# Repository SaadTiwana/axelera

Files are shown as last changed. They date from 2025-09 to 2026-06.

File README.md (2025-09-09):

# axelera
Notes and files for work on Axelera Metix M.2 on RK3588 board and using it to build an intelligent Marine surveillance Gimbal system.

The work was done as part of Axelera's Pioneer 10 : AI vision challenge.

https://community.axelera.ai/groups/project-challenge-recognize-react-27

The indidual directories contain all the files for each aspect of the project.

Read more details about the project here:

[PART 1]
https://community.axelera.ai/project-challenge-recognize-react-27/sauron-intelligent-marine-surveillance-system-pioneer-10-project-final-submission-part-one-1020

[PART 2]
https://community.axelera.ai/project-challenge-recognize-react-27/sauron-intelligent-marine-surveillance-system-pioneer-10-project-final-submission-part-two-1023

[PART 3]
https://community.axelera.ai/project-challenge-recognize-react-27/sauron-intelligent-marine-surveillance-system-pioneer-10-project-final-submission-part-three-1024

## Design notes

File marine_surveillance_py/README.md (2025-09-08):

# Maritime Surveillance System

A robust Python-based maritime surveillance system running on RK3588 with Axelera Metis M.2 AI accelerator, featuring real-time object detection, precise gimbal control, and intelligent restricted area monitoring with audio alerts.

## 🏗️ System Architecture

```
┌─────────────────┐    ┌─────────────────┐    ┌─────────────────┐
│   STM32 Gimbal  │◄──►│   RK3588 SBC    │◄──►│  USB Camera     │
│   Controller    │    │  ┌────────────┐ │    │  (/dev/video20) │
└─────────────────┘    │  │ Axelera     │ │    └─────────────────┘
                       │  │ Metis M.2   │ │
                       │  │ AI Engine   │ │
                       │  └────────────┘ │
                       └─────────────────┘
```

## 📁 Project Structure

```
Axelera_program/
├── main.py                 # 🚀 Main application orchestrator with alarm management
├── config.py              # ⚙️ Configuration management and validation
├── uart_comm.py           # 📡 UART communication with STM32 gimbal
├── scan_planner.py        # 🗺️ FOV-based scan planning with serpentine patterns
├── camera.py              # 📷 Camera capture with buffer management
├── detector.py            # 🎯 AI object detection with coordinate conversion
├── logger.py              # 📊 Detection logging and data persistence
├── monitor.py             # 🚨 Restricted area monitoring with audio alerts
├── settings.json          # 🔧 Configuration file with current settings
├── requirements.txt       # 📦 Python dependencies
├── documentation/         # 📚 System documentation and diagrams
├── utilities/             # 🛠️ Testing and utility scripts
└── README.md              # 📖 This documentation
```

## 🚀 Quick Start

### Prerequisites

1. **Hardware Requirements:**
   - RK3588 single-board computer
   - Axelera Metis M.2 AI accelerator
   - USB camera (tested with /dev/video20)
   - STM32-based gimbal controller
   - Bluetooth speaker (optional, for audio warnings)

2. **Software Requirements:**
   ```bash
   pip install opencv-python numpy pyserial
   pip install degirum  # Degirum SDK for object detection
   ```
Note: The voyager-sdk needs to be installed on the system and Metis device working properly. If the degirum sdk cannot find the Metis device, type "axdevice --refresh" from inside the voyager-sdk's venv.

### Configuration

Edit `settings.json` to configure your system:

```json
{
  "camera": {
    "device": "/dev/video20",
    "resolution": [1920, 1280],
    "fov_degrees": [8.28, 5.53]
  },
  "scan_area": {
    "azimuth_range": [-20.0, 20.0],
    "elevation_range": [-20.0, 0.0],
    "min_overlap_percentage": 0.1,
    "scan_cycles": 1
  },
  "restricted_areas": [
    {
      "name": "Bridge Entrance",
      "polygon": [
        [-45.0, -10.0],
        [-30.0, -5.0],
        [-15.0, -10.0],
        [-30.0, -15.0]
      ],
      "warning_threshold_seconds": 30,
      "classes": ["boat_small", "boat_medium"]
    },
    {
      "name": "Marine Sanctuary",
      "polygon": [
        [-45.0, -10.0],
        [-30.0, -5.0],
        [-15.0, -10.0],
        [-30.0, -15.0]
      ],
      "warning_threshold_seconds": 30,
      "classes": ["boat_large", "ship"]
    }
  ]
}
```

### Running the System

#### Continuous Monitoring Mode (Default)
```bash
python3 main.py
```

#### Single Scan Mode
```bash
python3 main.py --mode single
```

#### Hardware Testing Only
```bash
python3 main.py --test
```

#### Custom Configuration
```bash
python3 main.py --config my_settings.json --mode continuous
```

#### Live Video Feed (Camera Focusing)
```bash
python3 main.py --live-video
```
Use this mode to focus and adjust your camera before starting surveillance. The system will:
- Display a live video feed with a crosshair for focusing
- Show camera resolution and FPS information
- Allow you to adjust camera settings while viewing the feed
- Press Ctrl+C in the terminal to exit and return to normal operation

## ⚙️ Configuration Details

### Camera Configuration
- **device**: Video device path (e.g., `/dev/video20`)
- **resolution**: Camera resolution [width, height]
- **fov_degrees**: Camera field of view [azimuth, elevation] in degrees

### Scan Area Configuration
- **azimuth_range**: Azimuth scan range [min, max] in degrees
- **elevation_range**: Elevation scan range [min, max] in degrees
- **min_overlap_percentage**: Frame overlap percentage (0.0-1.0) for automatic step calculation from camera FOV
- **scan_cycles**: Number of complete scan cycles to perform (1/2/3/... or -1 for indefinite)

### Restricted Areas
- **name**: Human-readable area name
- **polygon**: List of [azimuth, elevation] points defining the area boundary
  - Supports any number of points (minimum 3 for a valid polygon)
  - Points should be specified in clockwise or counter-clockwise order
  - Supports complex shapes: triangles, rectangles, irregular polygons
  - Automatically closed by the system (connects last point to first)
- **warning_threshold_seconds**: Time threshold for triggering audio warnings
- **classes**: List of object classes to monitor (optional, monitors all classes if empty)
  - Example: `["boat_small", "boat_medium", "ship"]`
  - Only specified classes will trigger warnings in this area

### Gimbal Configuration
- **move_timeout_seconds**: Maximum time to wait for gimbal movement
- **settle_time_seconds**: Time to wait after movement for stabilization
- **max_retries**: Maximum retry attempts for failed movements

### Detection Configuration
- **model_path**: Path to Degirum model file
- **confidence_threshold**: Minimum confidence for detections (0.0-1.0)
- **tile_size**: Image tile size for processing large images
- **overlap**: Overlap between tiles (0.0-1.0)

## 🔧 Hardware Setup

### UART Connection
Connect the RK3588 UART to STM32:
- RK3588 TX → STM32 RX
- RK3588 RX → STM32 TX
- Ground connection
- Baud rate: 115200

### Camera Setup
1. Connect USB camera to RK3588
2. Verify device path: `ls /dev/video*`
3. Update `settings.json` with correct device path

### Audio Setup (Optional)
For Bluetooth speaker audio warnings:
```bash
# Install Bluetooth audio support
sudo apt-get install bluealsa

# Pair and connect Bluetooth speaker
bluetoothctl
# pair XX:XX:XX:XX:XX:XX
# connect XX:XX:XX:XX:XX:XX
```

## 📊 System Operation

### Scan Process
1. **Position Planning**: System calculates optimal scan positions
2. **Gimbal Movement**: Moves to each scan position with verification
3. **Image Capture**: Captures high-resolution image
4. **Object Detection**: Runs AI detection using Degirum SDK
5. **Data Logging**: Saves detections with position and timestamp
6. **Area Monitoring**: Checks for restricted area violations
7. **Audio Warnings**: Issues alerts for violations

### Detection Results
- **Real-time Display**: Shows detections on captured images
- **CSV Logging**: Saves all detections to timestamped files
- **Image Storage**: Saves annotated images for review
- **Statistics**: Tracks detection rates and patterns

## 🔍 Scan Planning and Execution

### Automatic Step Calculation
The system automatically calculates optimal scan steps based on:
- **Camera Field of View**: Uses actual camera FOV angles
- **Overlap Percentage**: Configurable frame overlap (default 10%)
- **Formula**: `step = FOV × (1 - overlap_percentage)`

Example: With 60° FOV and 10% overlap → step = 60° × 0.9 = 54°

### Vertical Serpentine Scan Pattern
- **Systematic Coverage**: Starts from top-left of scan area
- **Vertical Serpentine Movement**: Alternates direction on each column
  - Column 1: Top to bottom (down)
  - Column 2: Bottom to top (up)
  - Column 3: Top to bottom (down)
  - And so on...
- **Complete Coverage**: Ensures no gaps in surveillance area

### Scan Cycle Control
- **Finite Cycles**: Specify exact number of complete scans (1, 2, 3, etc.)
- **Indefinite Monitoring**: Set `scan_cycles: -1` for continuous operation
- **Progress Tracking**: Shows current cycle and total progress

### Restricted Area Handling
- **Full Coverage**: All positions in scan area are visited (no exclusions)
- **Monitoring vs Exclusion**: Restricted areas are monitored, not avoided
- **Class-Specific Alerts**: Only specified object classes trigger warnings per area
- **Flexible Polygons**: Support for complex shapes with 3+ vertices

## 🎯 Key Features

### Intelligent Scan Planning
- **FOV-based step calculation** using camera field of view and overlap percentage
- **Vertical serpentine scan pattern** for systematic coverage (top-left to bottom-right)
- **Automatic overlap management** to ensure no gaps in surveillance
- **Configurable scan cycles** (1-N cycles or indefinite monitoring)
- **Complete area coverage** including restricted zones (monitoring vs exclusion)

### Robust Gimbal Control
- **Position verification** after each movement with angle validation
- **Retry logic** for failed movements with configurable timeouts
- **Emergency stop** functionality with motor centering
- **UART communication** with CRC error checking and protocol validation

### Advanced Object Detection
- **Degirum SDK integration** for high-performance AI inference
- **Image tiling** for processing large images (1920x1280)
- **Coordinate system conversion** from normalized to azimuth/elevation angles
- **Confidence thresholding** to filter noise and false positives
- **Multi-class detection** for various maritime objects

### Restricted Area Monitoring
- **Polygon-based zones** supporting complex shapes (triangles to irregular polygons)
- **Class-specific monitoring** - monitor only specified object classes per area
- **Dwell time tracking** for persistent violations with configurable thresholds
- **Audio warnings** via Bluetooth speaker for immediate alerts
- **Visual alarm indicators** with red bounding boxes and status display
- **Comprehensive violation logging** with timestamps and object details

## 📈 Monitoring and Logging

### Real-time Statistics
- Detection counts and confidence scores
- Gimbal movement success rates
- System performance metrics
- Hardware status monitoring

### Data Export
- **CSV files** with detection data
- **Annotated images** for visual verification
- **System logs** for troubleshooting
- **Performance statistics** for optimization

## 🛠️ Troubleshooting

### Common Issues

#### 1. UART Communication Problems
```bash
# Check UART device
ls /dev/ttyS* /dev/ttyUSB*

# Test serial connection
python3 -c "import serial; s=serial.Serial('/dev/ttyS0', 115200, timeout=1); print('UART OK' if s.is_open else 'UART FAIL')"
```

#### 2. Camera Issues
```bash
# Check camera device
v4l2-ctl --list-devices
v4l2-ctl --list-formats-ext /dev/video20

# Test camera capture
ffmpeg -f v4l2 -i /dev/video20 -vframes 1 test.jpg

# Run comprehensive camera test
python3 utilities/camera_test.py
```

#### 3. Degirum SDK Issues
```bash
# Check Degirum installation (from inside degirum venv)
python3 -c "import degirum as dg; print('Degirum OK')"

degirum sys-info

# Verify model file
ls -la models/yolo_v5s_maritime
```

#### 4. Gimbal Movement Issues
- Check UART wiring and baud rate
- Verify STM32 is running and UARTProtocol is active
- Check gimbal angle limits in settings
- Monitor STM32 serial output for error messages

### Camera Testing and Debugging
The system includes comprehensive camera testing utilities:

```bash
# Run comprehensive camera test
python3 utilities/camera_test.py

# This tests:
# - Device existence and permissions
# - Multiple OpenCV backends (V4L2, ANY)
# - Different resolutions (640x480, 1280x720, 1920x1080, 1920x1280)
# - Frame capture capabilities
# - Camera properties and settings
# - Continuous capture stability
```

### Debug Mode
Enable detailed logging by modifying `settings.json`:
```json
{
  "logging": {
    "log_level": "DEBUG"
  }
}
```

### Camera Backend Fixes
If you encounter camera issues, the system automatically tries multiple OpenCV backends:
1. **V4L2 Backend** (recommended for Linux)
2. **ANY Backend** (auto-detection fallback)

The camera module includes:
- ✅ Multiple backend support
- ✅ Retry logic for failed captures
- ✅ Stabilization delays
- ✅ **Camera warm-up sequence** (discards first 10 frames)
- ✅ Comprehensive error handling
- ✅ Format and resolution testing

### Camera Warm-up Process
After opening the camera and setting resolution, the system automatically:
1. Waits 0.5 seconds for initial stabilization
2. Discards the first 10 frames to allow:
   - Auto-exposure adjustment
   - Auto-white balance stabilization
   - Auto-focus completion (if available)
   - Overall camera parameter optimization
3. Ensures consistent image quality for detection

## 🔧 API Reference

### GimbalController
```python
gimbal = GimbalController(config)
gimbal.connect()                    # Establish UART connection
gimbal.get_angles()                 # Get current angles (pitch, yaw)
gimbal.set_angles(pitch, yaw)       # Set target angles
gimbal.move_to_position(az, el)     # Move to azimuth/elevation
```

### ObjectDetector
```python
detector = ObjectDetector(config)
detector.initialize()               # Initialize Degirum model
detections = detector.detect_with_tiling(image)  # Run detection
```

### AreaMonitor
```python
monitor = AreaMonitor(config)
warnings = monitor.process_detections(detections, scan_pos)
```

## 📝 Development Notes

### Adding New Features
1. Create new module in appropriate file
2. Update `settings.json` for configuration
3. Integrate with main orchestrator in `main.py`
4. Add proper error handling and logging

### Performance Optimization
- **Automatic FOV-based step calculation** eliminates manual tuning
- **Overlap percentage adjustment** for coverage vs speed trade-off
- **Scan cycle configuration** for mission-specific operation duration
- **Class-specific monitoring** reduces false positive processing
- **Flexible polygon definitions** for precise restricted area boundaries
- Monitor CPU/GPU usage with Axelera tools

### Safety Considerations
- Implement proper emergency stop procedures
- Add watchdog timers for critical operations
- Validate all input parameters
- Handle hardware failures gracefully

## 📄 License

This project is part of the maritime surveillance system for RK3588 with Axelera Metis M.2.

## 🤝 Contributing

1. Fork the repository
2. Create a feature branch
3. Add comprehensive tests
4. Submit a pull request

## 📞 Support

For issues and questions:
1. Check the troubleshooting section
2. Review system logs
3. Verify hardware connections
4. Check configuration settings

---

**System Status**: ✅ Production Ready with Enhanced Features
**Hardware**: RK3588 + Axelera Metis M.2 + STM32 Gimbal Controller
**Software**: Python 3.8+ with Degirum SDK + OpenCV
**Key Features**: Coordinate conversion, audio alerts, visual alarms, robust error handling, real-time monitoring

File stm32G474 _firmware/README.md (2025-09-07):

STM32G474 firmware for the 2 axis gimbal

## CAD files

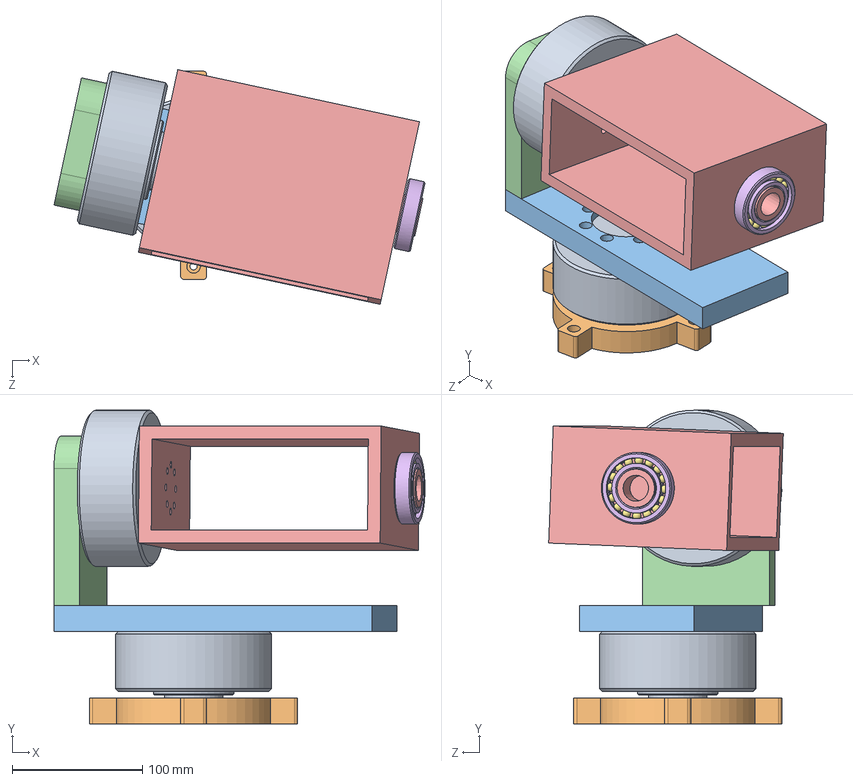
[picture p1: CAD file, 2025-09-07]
mechanical_design/GimbalAssembly.SLDASM
285.0 x 241.0 x 180.3 mm
RMD_L_12025 x 2
BottomBase
MiddleGimbalPart
VerticalMotorPlate
InnerGimbalPlatform
ball bearing(6006)-body.stp
ball bearing(6006)-ball.stp x 16

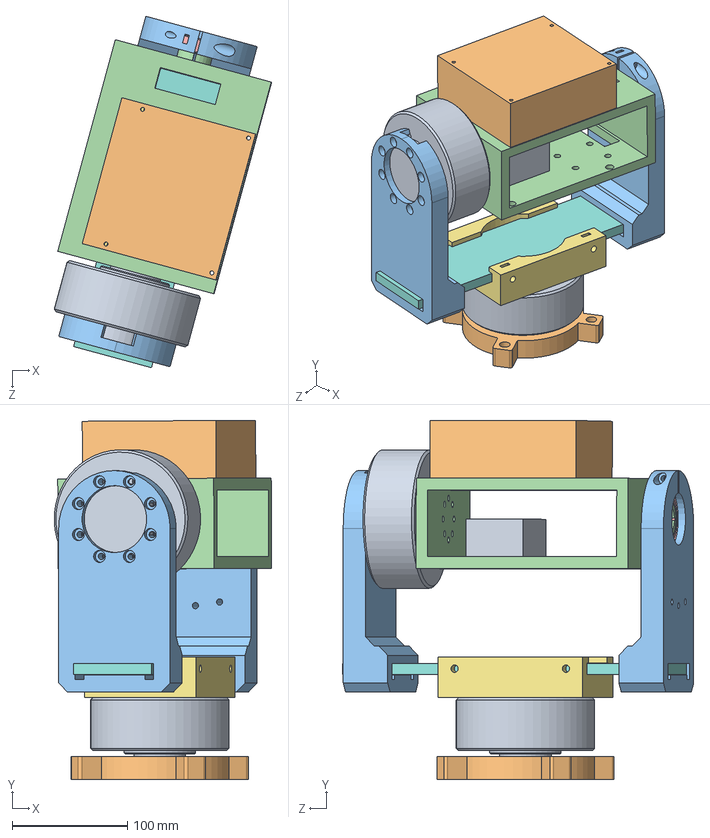
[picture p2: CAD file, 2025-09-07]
mechanical_design/GimbalAssembly_V2.SLDASM
188.4 x 311.0 x 304.5 mm
RMD_L_12025 x 2
BottomBase
VerticalMotorPlate x 2
InnerGimbalPlatform
ball bearing(6006)-body.stp
ball bearing(6006)-ball.stp x 16
YawMotorAttachment
AluminumBlackPlate
ControlBoard
AetinaRK3588_With15mmSpacers

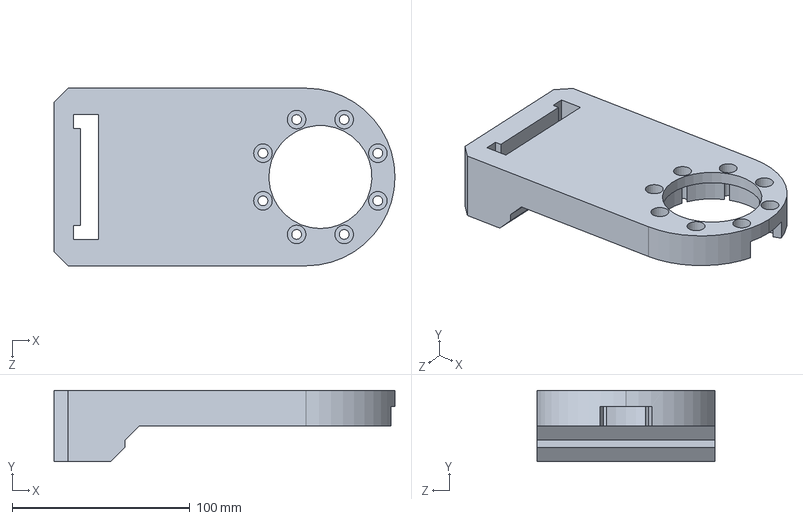
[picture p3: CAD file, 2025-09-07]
mechanical_design/VerticalMotorPlate.SLDPRT
192.0 x 40.0 x 100.0 mm

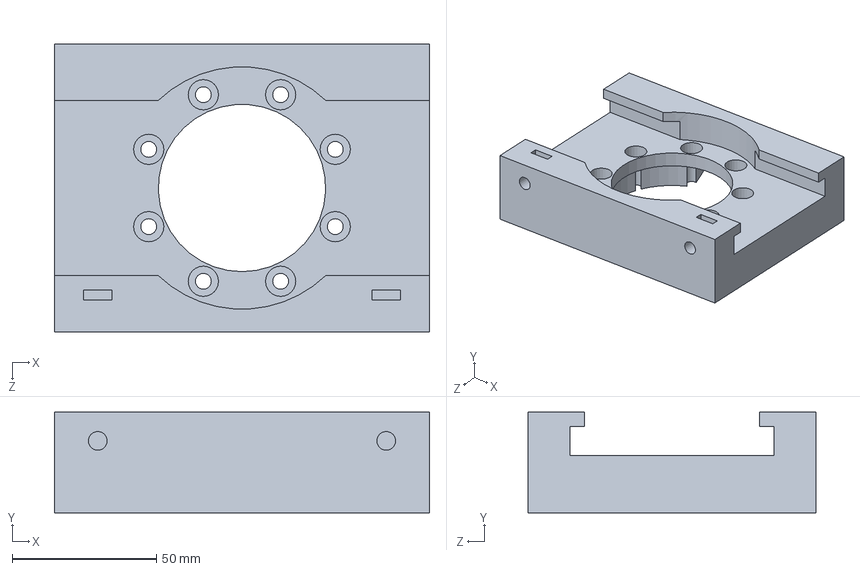
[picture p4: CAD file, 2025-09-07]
mechanical_design/YawMotorAttachment.SLDPRT
130.0 x 35.0 x 100.0 mm

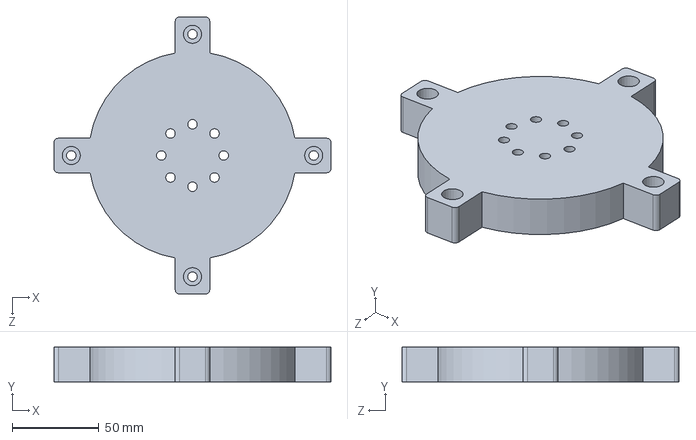
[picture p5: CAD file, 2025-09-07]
mechanical_design/BottomBase.SLDPRT
160.0 x 20.0 x 160.0 mm

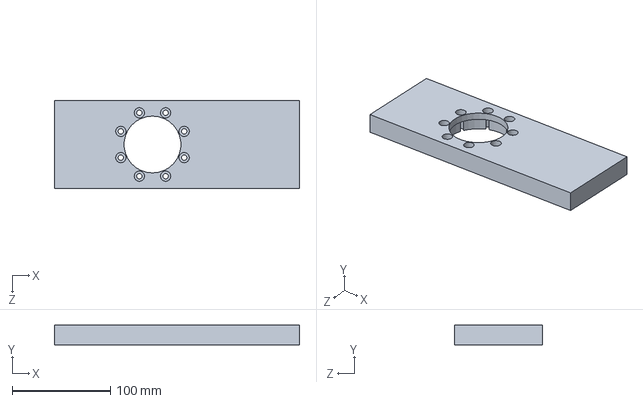
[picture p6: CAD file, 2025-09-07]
mechanical_design/MiddleGimbalPart.SLDPRT
250.0 x 20.0 x 90.0 mm

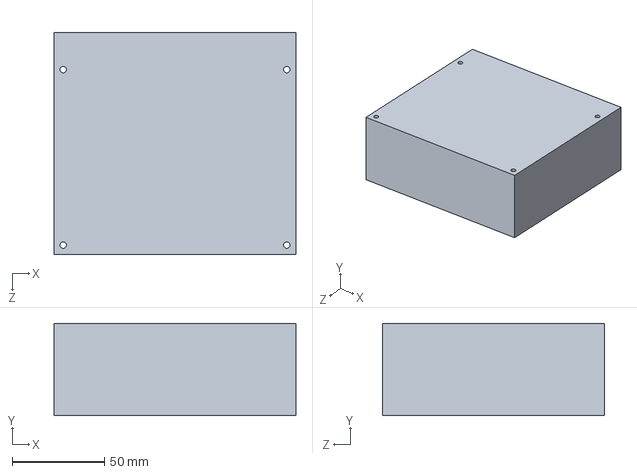
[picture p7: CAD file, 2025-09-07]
mechanical_design/AetinaRK3588_With15mmSpacers.SLDPRT
131.0 x 50.0 x 120.0 mm

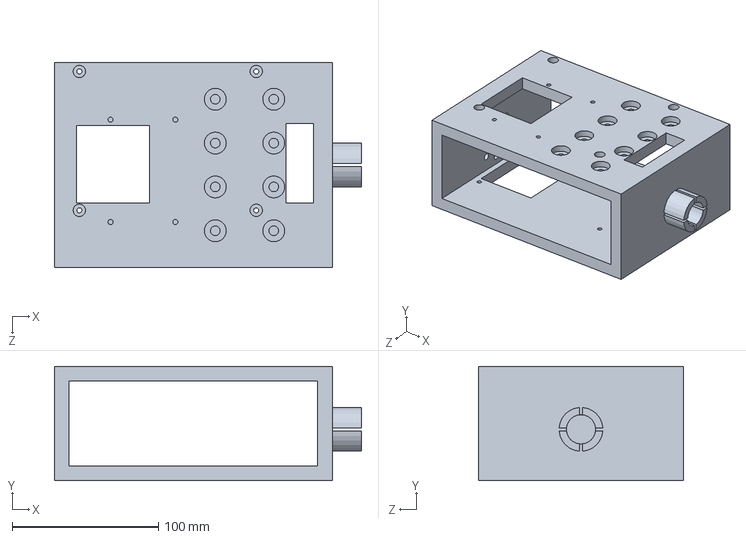
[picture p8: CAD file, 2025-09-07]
mechanical_design/InnerGimbalPlatform.SLDPRT
210.0 x 78.0 x 140.0 mm

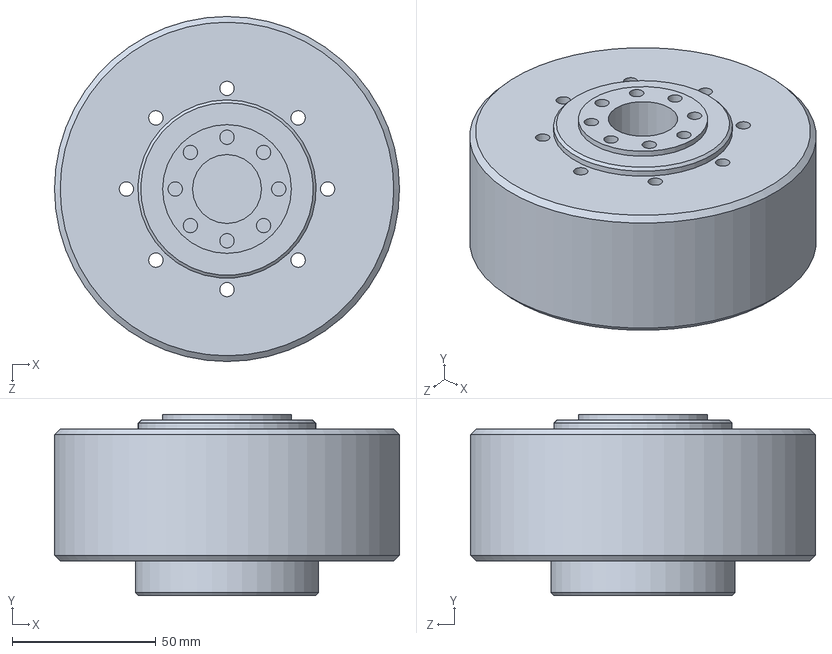
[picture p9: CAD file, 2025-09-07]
mechanical_design/RMD_L_12025.SLDPRT
120.0 x 63.0 x 120.0 mm

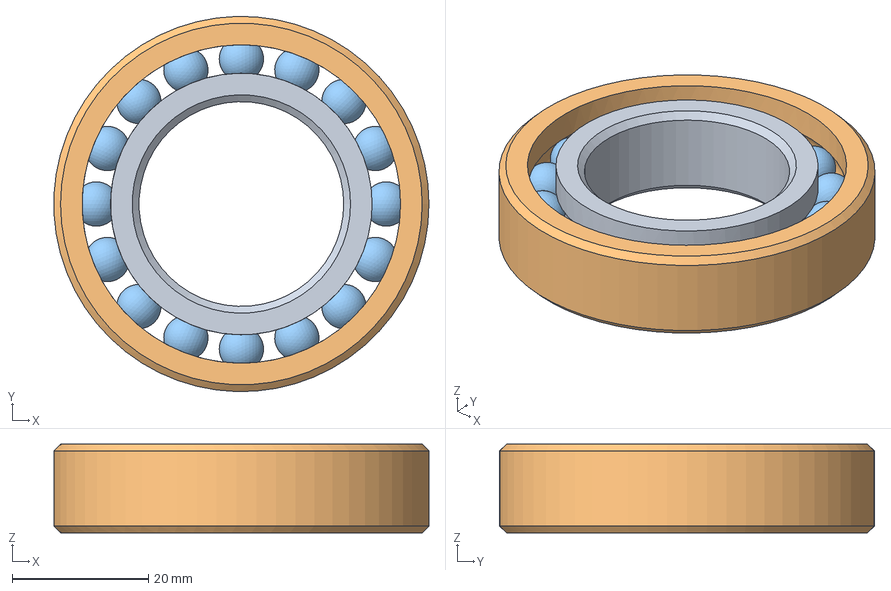
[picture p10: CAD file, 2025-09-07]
mechanical_design/ball bearing(6006).stp
55.0 x 55.0 x 13.0 mm
ball bearing(6006)-body
ball bearing(6006)-ball x 16

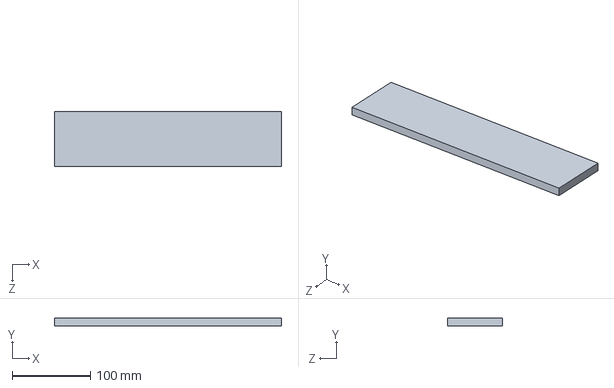
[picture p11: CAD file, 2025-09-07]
mechanical_design/AluminumBlackPlate.SLDPRT
290.0 x 9.60 x 70.0 mm

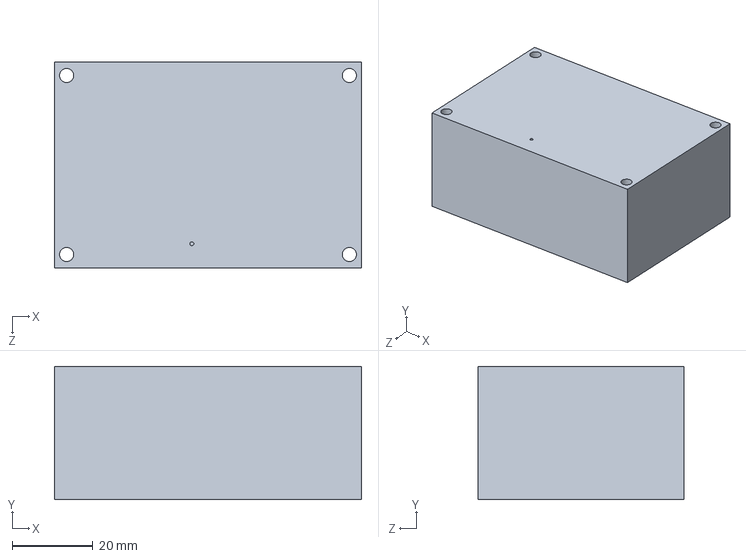
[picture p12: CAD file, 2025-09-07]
mechanical_design/ControlBoard.SLDPRT
76.0 x 33.0 x 51.0 mm

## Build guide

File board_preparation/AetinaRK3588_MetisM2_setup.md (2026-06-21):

# Introduction

This file details the full procedure to (re-)image an Aetina RK3588 board fitted with Axelera Metis M.2 accelerator card and prepare it for usage. Information here has been gathered from Axelera help pages, community posts and also from information shared by the very helpful [Shabaz](https://github.com/shabaz123) . I had the 16GB RAM version of the Aetina RK3588 board. All the instructions will also hold for the 8GB version, except that swapfile should also be enabled for the 8GB version.

# Flashing the board

These instructions hold for the Aetina RK3588 board. The instructions are taken from the Axelera page:

https://support.axelera.ai/hc/en-us/articles/25556440050194-System-Imaging-Guide-Aetina-RK3588

A Ubuntu x86/x64 "host" system is needed for this procedure (the RK3588 board cannot itself be used for this). I used ubuntu 22 "live" usb disk running on a laptop (this prevents needing to install the OS to the machine). I also tried with a Virtual Machine (Vmware), which worked fine as well.

Inside the host ubuntu, download the image (get latest link from page above, in case there is a newer version). Below is link to image as of July 2025:

https://axelera-public.s3.eu-central-1.amazonaws.com/host-images/v1.0.0-a6-0-g544580a49/Aetina-ubuntu-22.04-v1.1.tgz

`wget https://axelera-public.s3.eu-central-1.amazonaws.com/host-images/v1.0.0-a6-0-g544580a49/Aetina-ubuntu-22.04-v1.1.tgz`

After downloading the file, do this:
```
sudo tar -xvzf Aetina-ubuntu-22.04-v1.1.tgz 
cd rockdev
chmod +x upgrade_tool
```

Install jumpter between pins 2,3 of DEBUG3 header on board, connect USB-C port of board to host system (using USB-A to USB-C cable). Then power on the board. After several seconds, remove the jumper from the board. 

Run following commands to check board is connected and status:

`./upgrade_tool LD` 

Axelera link mentioned the board should appear like this, in "Loader" mode:

>List of rockusb connected(1)
>
>DevNo=1 Vid=0x2207,Pid=0x350b,LocationID=31     Mode=Loader     SerialNo=1da8b74954605d1d

However, my board was going into "Maskrom" mode only. 

>List of rockusb connected(1)
>
>DevNo=1 Vid=0x2207,Pid=0x350b,LocationID=11     Mode=Maskrom     SerialNo=

However, I found out that it didn't matter actually. I was able to proceed with firmware update as normal. To start the flashing, use command:

`./flash.sh`

The process will finish like this (last few lines only)
>Download image ok.
>
>---- reset device ----
>
>Reset Device OK. 

Now, remove USB-C cable and unplug power, then plug it back in (power-cycle, and not just restart).

Connect to Mouse/Keyboard, HDMI cable and power on.

# Setting Default User and Auto-login

By default, the image comes with two users "firefly" and "aetina", and the board boots into "firefly" user on power up. Since I noticed that a lot of documentation uses the "aetina" user, I decided it's best to set "aetina" as the default user so that the board conveniently boots into it on power up.

The relevant setting is in the file `/etc/lightdm/lightdm.conf.d/20-autologin.conf`. Open this file using any text editor (vi/vim/nano/gEdit, etc) and look for the line `autologin-user=firefly`. Change it to `autologin-user=aetina`, and then reboot the board `sudo reboot`.

Once the board reboots, it will auto-login into the "aetina" user, which can be confirmed by executing the command `whoami` in a terminal. At this point, if you want to remove the firefly user completely, type following command in the terminal:

`sudo deluser --remove-home firefly`

This will remove (delete) the user "firefly" and also remove the home folder for the user (this helps recover some space on the flash).

# Getting Wifi + BT to work

Before going further, it makes things easy to connect to internet with an Ethernet cable (can also share internet from the Ubuntu or windows host PC if router is far). 

Another easy alternative for getting internet access is using the RTL8188 USB dongle provided by Axelera to connect to internet. Use instructions provided by Shabaz:

https://github.com/shabaz123/rtl8188eus/blob/master/README.md 

Note that speed from this dongle is not great (works on 2.4Ghz only) but ok to get internet quickly.

To get better speed, I installed a RTL8822CE based M.2 card (5.8Ghz+ 2.4Ghz Wifi, Bluetooth) on the back side of the board - Credit to Shabaz for the idea!

The driver for this is available in the "linux-firmware" package inside the linux git. However ,the whole package is more than a GB in size and not suitable to download to an embedded board like this. Instad, we can manually download and install the driver files.

Download the latest driver files from the linux repository (click file name, then download raw/plain - very important to do like this. Right-click->save does not download file correctly):

https://git.kernel.org/pub/scm/linux/kernel/git/firmware/linux-firmware.git/tree/rtw88

We only need two files:
>rtw8822c_fw.bin
>
>rtw8822c_wow_fw.bin

Alternatively, we can download via wget in terminal (link used are raw/plain file links, which downloads the files correctly):
```
wget https://git.kernel.org/pub/scm/linux/kernel/git/firmware/linux-firmware.git/plain/rtw88/rtw8822c_fw.bin
wget https://git.kernel.org/pub/scm/linux/kernel/git/firmware/linux-firmware.git/plain/rtw88/rtw8822c_wow_fw.bin
```

Next, with a terminal open in the directory where files were downloaded, run following commands:
```
sudo mkdir -p /lib/firmware/rtw88
sudo mv rtw88*.bin /lib/firmware/rtw88/
sudo depmod -a
sudo modprobe rtw88_8822ce
sudo reboot
```

The wifi card should be functioning now and you can search and connect to a network using the toolbar on top-right of Ubuntu GUI. 

For more detailed instructions, refer to:

https://github.com/shabaz123/axelera/tree/main/rtw88

For this card, I did not have to do anything to get the bluetooth to work - it worked out of the box.

# Set up SD card to extend storage and swap file
The RK3588 board comes with 32GB of Flash storage. After the ubuntu 22 image is installed on the board it only leaves ~10GB storage available, which is quite small and fills up really quickly. Hence extending it with a fast SD card or a M.2 SSD is very important. 

Main article to refer to:

https://support.axelera.ai/hc/en-us/articles/25556514922514-Solving-Storage-Space-Issues-on-Aetina-Evaluation-System

Some commands have been modified, though. 

Insert sdcard, and confirm presence by using command:

`lsblk -f`

The SD card will appear as mmcblk1p1 (or something similar?). In instructions below we will assume it is "mmcblk1p1".

```
sudo mkfs.ext4 -F -L microsd /dev/mmcblk1p1

cd /mnt
sudo mkdir microsd
sudo bash -c "echo \"LABEL=microsd /mnt/microsd ext4 defaults,user,exec,nofail 0 2\" >> /etc/fstab"
sudo mount /mnt/microsd
sudo chown aetina:aetina /mnt/microsd
```

Next, we want to link some of the main folders used by Axelera sdk, etc to the SD card so that the they dont end up using up the EMMC.

First we remove the /axelera folder and recreate as a symbolic link to the SD card
```
sudo rm -rf /axelera
mkdir /mnt/microsd/axelera
sudo ln -s /mnt/microsd/axelera /axelera

```

Next, to prevent Axelera SDk from filling up the /home/aetina/.cache/axelera/data folder, we link it to SD card also

```
sudo mkdir /mnt/microsd/aetina_cache_axelera
sudo chown aetina:aetina /mnt/microsd/aetina_cache_axelera

ln -s /mnt/microsd/aetina_cache_axelera /home/aetina/.cache/axelera
mkdir /mnt/microsd/aetina_cache_axelera/data

```

# Setting up SWAP file

Setting up SWAP file is recommended for the 8GB RAM version of the Aetina RK3588 board. However, I found that the board shipped to me by Axelera is the 16GB RAM Aetina RK3588 boards, hence this was not needed. This can be confirmed by typing the following in a console:

`free -h`

Look at the 'total' under command output. In my case, it showed "15Gi" which points to it having 16GB RAM.

For the 8GB version board, follow the procedure at this link:
https://support.axelera.ai/hc/en-us/articles/25556440050194-System-Imaging-Guide-Aetina-RK3588

# Install Docker

Note: Don't install Docker until you've mounted either a microSD card, or M.2 SSD as extra storage, and created /axelera as a symbolic link to that storage. Otherwise, Docker will make use of the SBC's embedded memory, which is insufficient.

Once you have mounted the extra storage and created the /axelera link, follow the procedure here:

https://docs.docker.com/engine/install/ubuntu/

Axelera recommends using the method under "Install using the apt repository" heading on the linked page.

## Resolving ‘you have held broken packages’
When you start typing the Docker installation steps, you may see a **you have held broken packages** message. The solution is to type the following as a user (e.g. as aetina user), and then you can re-do the Docker installation.

```
apt-mark showhold | tee ~/apt-holds.backup
sudo xargs -r apt-mark unhold < ~/apt-holds.backup
sudo apt update
sudo apt --fix-broken install
sudo apt full-upgrade
rm ~/apt-holds.backup
```

# Install Voyager SDK

The latest procedure for this is detailed at the Axelera link:

https://github.com/axelera-ai-hub/voyager-sdk/blob/HEAD/docs/tutorials/install.md

Very importantly, I changed directory to /axelera before cloning the SDK so that all data is downloaded to the SD card instead of EMMC.

```
cd /axelera
<proceed with git clone & installation commands>
```

After this, I proceeded with following the commands in the Axelera link.

Important observation: All packages did not get installed the first time I executed the ./install.sh script in Voyager SDK. There were errors about "holding broken packages" (answer "y" when it asks). My solution was to keep re-executing the install script, and every time it would go further, until finally everything was installed correctly.

Note that any time we need to use the Voyager SDK, we need to open a terminal, and then execute the following commands to activate the virtual environment:

```
cd /axelera/voyager-sdk/
source venv/bin/activate
```

# Upgrade M.2 Metis module firmware (if needed)

The Metis M.2 device runs its own "firmware" and "board controller firmware". The version on the installed M.2 Metis module can be checked by executing command `axdevice` in a terminal, AFTER activating the voyager venv:

```
cd /axelera/voyager-sdk/
source venv/bin/activate

axdevice
```

Example output:

>Device 0: metis-0:1:0 1GiB m2 flver=1.3.2 bcver=1.4 clock=800MHz(0-3:800MHz) mvm=0-3:100%

"flver" displays the firmware version, and "bcver" displays the board controller firmware version.

Important Note: Due to some risk of bricking the device in case of interruption or power failure while updating, only update the firmwares if your device is running an older firmware.

To update navigate to `Github -> axelera-ai-hub -> voyager-sdk -> docs -> tutorials -> firmware_flash_update.md` and follow the procedure detailed there. Since the exact commands/procedure may change in later releases, I am not replicating the commands here. 

# Configure for remote access

Remote access is very important for embedded computers, and different tools work better/worse on different platforms so I prefer to document this. In my case my remote access tool of choice at the time of this writing is "NoMachine". To install, go to `www.nomachine.com` and navigate to the download page. Among platofrms, choose "NoMachine for ARM". Among the options under "ARM 64-bit", choose "NoMachine for ARM DEB (arm64)". It's very important to select this particular option, since the others did not get installed on the RK3588 board.

Once downloaded, go to Downloads folder and then install (adjust name of .deb file in command below as per actual)

```
cd ~/Downloads/
sudo dpkg -i nomachine_XXXXXXXXXXXXXXXX.deb
```

One issue I saw was that after every reboot, the NoMachine services needed to be manually restarted, otherwise it would not allow remote connections. This is solved by typing the following command in a terminal

`sudo /etc/NX/nxserver --startmode nxd automatic`

Now it should be possible to connect to the board after booting without any manual intervention.

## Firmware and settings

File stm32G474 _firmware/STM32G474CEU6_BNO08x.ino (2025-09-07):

/*
Dependency libraries:

ACANFD_STM32 (Pierre Molirano). Tested with 1.1.2-rc1
Adafruit BNO08x (Adafruit). Tested with 1.2.5

Arduino IDE settings:
Board : Generic STM32G4 series
Port : <Actual>
Board Part Number: WeAct G474CE
Upload method: STM32CubeProgrammer (DFU)
USB support: CDC Generic Serial 
U(S)ART support: Enabled (Generic 'Serial')
*/

#include <iostream>
#include <Wire.h>
#include "motorController.hpp"
#include "ahrs.hpp"
#include "pid.hpp"
#include "lowpass_filter.hpp"
#include "UARTProtocol.hpp"
#include "SystemStatus.hpp"

// IMPORTANT:<ACANFD_STM32.h> should be included only once in a sketch, generally from the .ino file
//   From an other file, include <ACANFD_STM32_from_cpp.h>
#include <ACANFD_STM32.h>
// https://github.com/pierremolinaro/acanfd-stm32/blob/main/extras/acanfd-stm32.pdf
// Default TxCAN pins are used:
//   - fdcan1 (default pins): PA12 (TX), PA11 (RX) -> Used by USB on WeAct STM32G474 board
//   - fdcan2 (default pins): PB6  (TX), PB5  (RX)
//   - fdcan3 (default pins): PA15 (TX), PA8  (RX)
#define FDCAN1_TX PA12 
#define FDCAN1_RX PA11

#define FDCAN2_TX PB13
#define FDCAN2_RX PB12


#define I2C3_SCL PA8
#define I2C3_SDA PC11
TwoWire Wire3(I2C3_SDA, I2C3_SCL);

AHRS ahrs(Wire3);

// UART options:
//    USART1 TX (PA9), RX (PA10)  -> Pins available on WeAct STM32G474      (HardwareSerial "Serial1")
//    USART2 TX (PA2), RX (PA3)   -> Pins available on WeAct STM32G474      (HardwareSerial "Serial2")
//    USART3 TX (PB10), RX (PB11) -> Pins shared with Qspi flash (if used?) (HardwareSerial "Serial3")
// HardwareSerial Serial_sbc(PA3, PA2);  // RX, TX
// HardwareSerial Serial_debug(PA10, PA9);   // RX, TX
HardwareSerial Serial_debug(PA3, PA2);  // RX, TX
HardwareSerial Serial_sbc(PA10, PA9);   // RX, TX




/*

Angles are commonly defined according to the right-hand rule. Namely, they have positive values 
when they represent a rotation that appears clockwise when looking in the positive direction of the axis, 
and negative values when the rotation appears counter-clockwise. 

We use ENU frame for now (used in Land vehicles). X axis points forward, Y points left and z points up.

*/




// From: https://doc.synapticon.com/circulo/tutorials/tuning_guides/position_controller_with_cascaded_structure.html
// By default, the integral limit of the velocity controller should be set to motor maximum torque in [mNm], 
// and the integral limit of position controller should be set to motor maximum velocity in [rpm] (dps in our case?).
// Note to self: Adjust units as per our own values


// -------------- PITCH AXIS --------------
// --- velocity PID controller parameters and instance ---
float pitch_vel_P     = 0.01;
float pitch_vel_I     = 0.0;
float pitch_vel_D     = 0.0;
float pitch_vel_ramp  = 0.0;   // Disabled if 0.0
float pitch_vel_limit = 0.5;    // in Amperes if output is Torque current. in deg/s if output is angular velocity.
// Velocity pid controller (output will be velocity or torque command)
PIDController pidc_pitch_vel = PIDController(pitch_vel_P, pitch_vel_I, pitch_vel_D, pitch_vel_ramp, pitch_vel_limit);

float lpf_Tf_gyroY = 0.01; // Y axis gyro LPF time constant in seconds
LowPassFilter lpf_gyroY = LowPassFilter(lpf_Tf_gyroY); // For pitch axis, we use Y axis gyro

// --- Position PID controller parameters and instance ---
float pitch_pos_P     = 0.1;
float pitch_pos_I     = 0.1;
float pitch_pos_D     = 0.0;
float pitch_pos_ramp  = 0.0; // Disabled if 0.0
float pitch_pos_limit = 0.05;  // in deg? if output is angular velocity.

// Pitch Position controller (output will be a velocity command - dps)
PIDController pidc_pitch_pos = PIDController(pitch_pos_P, pitch_pos_I, pitch_pos_D, pitch_pos_ramp, pitch_pos_limit); 

float pitch_pos_tgt_startup = 0.0;


// -------------- YAW AXIS --------------
// --- velocity PID controller parameters and instance ---
float yaw_vel_P     = 0.1;
float yaw_vel_I     = 0.0;
float yaw_vel_D     = 0.0;
float yaw_vel_ramp  = 0.0;   // Disabled if 0.0
float yaw_vel_limit = 2.0;    // in Amperes if output is Torque current. in deg/s if output is angular velocity.
// Velocity pid controller (output will be velocity or torque command)
PIDController pidc_yaw_vel = PIDController(yaw_vel_P, yaw_vel_I, yaw_vel_D, yaw_vel_ramp, yaw_vel_limit);

// --- Position PID controller parameters and instance ---
float yaw_pos_P     = 0.1; //10.0
float yaw_pos_I     = 0.1; //5.0
float yaw_pos_D     = 0.0; //0.0
float yaw_pos_ramp  = 0.0; // Disabled if 0.0
float yaw_pos_limit = 1.0; //10.0

// Position controller (output will be a velocity command - dps)
PIDController pidc_yaw_pos = PIDController(yaw_pos_P, yaw_pos_I, yaw_pos_D, yaw_pos_ramp, yaw_pos_limit); 

float yaw_pos_tgt_startup = 0.0;

// -------------- STABILIZATION FLAGS --------------
bool STABILIZE_ON_START = false; // MASTER SWITCH. Always keep false (to be turned on manually via serial command)
bool STABILIZE_PITCH = true;
bool STABILIZE_YAW = true;


bool MOTION_MODE_BASIC = true; // If true only position control is used and no IMU based stabilization is done. If false, cascaded position and velocity control is used.


// FLAGS that track current states
bool DISP_LV = false; // Show live variable display on Serial port or not


// Class variables
MotorController motorController;
SystemStatus sysStatus;
UARTProtocol sbcInterface(Serial_sbc, sysStatus, &Serial);  // Pass pointer to Serial and stabilize flag

// Below are in MOTOR position coordinates, not AHRS coordinates
#define POS_LIM_PITCH_DEG_MIN -30.0 
#define POS_LIM_PITCH_DEG_MAX +90   

#define POS_LIM_YAW_DEG_MIN -90.0
#define POS_LIM_YAW_DEG_MAX +90.0


// Measure loop execution frequency
unsigned long lastTime = 0;
unsigned long loopCount = 0;
unsigned long executionFreq_Hz = 0;

unsigned long loopCount_ahrs = 0;

void stopAllMotion() {
  //motorController.SetMotorVelocityClosedLoop_blocking(MotorController::MOT_PITCH, 0);
  //motorController.SetMotorVelocityClosedLoop_blocking(MotorController::MOT_YAW, 0);

  // I suspect the setting velocity to zero at beginning may be causing sudden movements of the motor(s). Not confirmed. Let's try torque instead.
  // motorController.SetMotorTorqueCurrentClosedLoop_blocking(MotorController::MOT_PITCH, 0.0);
  //motorController.SetMotorTorqueCurrentClosedLoop_blocking(MotorController::MOT_YAW, 0.0);

  if (false) {
    /******Non blocking *******/
    motorController.SetMotorTorqueCurrentClosedLoop_withCallback(MotorController::MOT_PITCH, 0.0, nullptr);
    motorController.SetMotorTorqueCurrentClosedLoop_withCallback(MotorController::MOT_YAW, 0.0, nullptr);

  } else {
    /*****Blocking******/
    motorController.SetMotorTorqueCurrentClosedLoop_blocking(MotorController::MOT_PITCH, 0.0);
    motorController.SetMotorTorqueCurrentClosedLoop_blocking(MotorController::MOT_YAW, 0.0);
  }
}


void setup() 
{
  Serial.begin(115200);
  //while(!Serial) delay(10); // Causes code to not execute if serial port is not opened. 
  delay(5000);
  Serial.println();
  Serial.println("Tracker Program Beginning...");

  Serial.println("Setting AHRS ...");
  ahrs.begin();
  
  delay(100);

  sysStatus.stabilize = STABILIZE_ON_START;

  
  motorController.begin();
  delay(1000);
  Serial.println("Setting motor(s) to zero");

  sbcInterface.begin(115200);

  Serial_debug.begin(115200);

  // Stop motor(s) in case motors have an active command from before controller booting up.
  stopAllMotion();

  // Send to zero position
  // VERY IMPORTANT: The Motors should already be zeroed before this
  motorController.SetMultiturnMotorPosition_blocking(MotorController::MOT_PITCH, 0, 20);
  motorController.SetMultiturnMotorPosition_blocking(MotorController::MOT_YAW, 0, 20);

  delay(5000);

  // Turn off motors
  motorController.SetMotorTorqueCurrentClosedLoop_blocking(MotorController::MOT_PITCH, 0.0);
  motorController.SetMotorTorqueCurrentClosedLoop_blocking(MotorController::MOT_YAW, 0.0);
  
  // Load Initial Target angles to the sysStatus variables. Later they will be changed by sbc program
  sysStatus.mot_angle_pitch_deg_target = pitch_pos_tgt_startup;
  sysStatus.mot_angle_yaw_deg_target = yaw_pos_tgt_startup;

  lastTime = micros();
}



/*
EXAMPLE SERIAL COMMANDS:
SET PID PITCH POS P 7.5
SET PID PITCH POS LIM 1
SET PID YAW VEL P 0.2
SET PID PITCH VEL LIM 100
TOGGLE DISP_LV
SET TARGET PITCH -10.0
SET TARGET YAW 15.0
SET STABILIZE ON
*/
void handleSerialCommands() {
  static String inputLine = "";
  while (Serial.available()) {
    char c = Serial.read();
    if (c == '\n' || c == '\r') {
      if (inputLine.length() > 0) {
        inputLine.trim();

        // Tokenize the input
        int tokenCount = 0;
        String tokens[8];
        int fromIndex = 0;
        while (fromIndex < inputLine.length() && tokenCount < 8) {
          int spaceIdx = inputLine.indexOf(' ', fromIndex);
          if (spaceIdx == -1) spaceIdx = inputLine.length();
          tokens[tokenCount++] = inputLine.substring(fromIndex, spaceIdx);
          fromIndex = spaceIdx + 1;
        }

        if ((tokenCount == 6) && (tokens[0] == "SET") && (tokens[1] == "PID")) {
          String axis = tokens[2];
          String loop = tokens[3];
          String param = tokens[4];
          float value = tokens[5].toFloat();
          PIDController* pid = nullptr;
          if (axis == "PITCH" && loop == "POS") pid = &pidc_pitch_pos;
          if (axis == "PITCH" && loop == "VEL") pid = &pidc_pitch_vel;
          if (axis == "YAW" && loop == "POS") pid = &pidc_yaw_pos;
          if (axis == "YAW" && loop == "VEL") pid = &pidc_yaw_vel;
          if (pid) {
            if (param == "P") pid->P = value;
            else if (param == "I") pid->I = value;
            else if (param == "D") pid->D = value;
            else if (param == "LIM") pid->limit = value;
            else if (param == "RAMP") pid->output_ramp = value;
            Serial.println("OK");
          } else {
            Serial.println("Unknown PID target");
          }

        } else if ((tokenCount == 4) && (tokens[0] == "SET") && (tokens[1] == "TARGET")) {
          String axis = tokens[2];
          float value = tokens[3].toFloat();
          if (axis == "PITCH") {
            sysStatus.mot_angle_pitch_deg_target = value;
            Serial.print("Pitch target set to ");
            Serial.println(sysStatus.mot_angle_pitch_deg_target, 3);
          } else if (axis == "YAW") {
            sysStatus.mot_angle_yaw_deg_target = value;
            Serial.print("Yaw target set to ");
            Serial.println(sysStatus.mot_angle_yaw_deg_target, 3);
          } else {
            Serial.println("Unknown axis for target");
          }

        } else if ((tokenCount == 3) && (tokens[0] == "SET") && (tokens[1] == "STABILIZE")) {
          String value = tokens[2];
          if (value == "ON") {
            sysStatus.stabilize = true;
            Serial.println("STABILIZE set to ON");
          } else if (value == "OFF") {
            sysStatus.stabilize = false;
            Serial.println("STABILIZE set to OFF");
          } else {
            Serial.println("Invalid value for STABILIZE (use ON or OFF)");
          }        
        
        } else if (inputLine.startsWith("TOGGLE DISP_LV")) {
          DISP_LV = !DISP_LV;
          Serial.print("DISP_LV is now ");
          Serial.println(DISP_LV ? "ON" : "OFF");
        } else {
          Serial.println("Invalid command");
        }
        inputLine = "";
      }
    } else {
      inputLine += c;
    }
  }
}


void cb_onPitchMotorPosition(uint motor_id, int status, const uint8_t* data) 
{
  // Although it should not happen, let's confirm motor ID anyway
  if (motor_id != MotorController::MOT_PITCH) {
    Serial.print("BUG - Received pitch motor callback for wrong motor ID: ");
    Serial.println(motor_id, HEX);
    return;
  }

    if (status != MotorController::STATUS_OK || !data) {
        Serial.print("Error retrieving position for PITCH motor, Status: ");
        Serial.println(status);
        return;
    }

    float multiturnAngle_deg = motorController.DecodeMultiturnMotorPositionReply(data);
      sysStatus.mot_angle_pitch_deg = multiturnAngle_deg;
      // Serial.print("(Callback) PITCH Motor pos: ");
      // Serial.println(multiturnAngle_deg, 3);
}

void cb_onYawMotorPosition(uint motor_id, int status, const uint8_t* data) 
{
  // Although it should not happen, let's confirm motor ID anyway
  if (motor_id != MotorController::MOT_YAW) {
    Serial.print("BUG - Received yaw motor callback for wrong motor ID: ");
    Serial.println(motor_id, HEX);
    return;
  }

    if (status != MotorController::STATUS_OK || !data) {
        Serial.print("Error retrieving position for YAW motor, Status: ");
        Serial.println(status);
        return;
    }

    float multiturnAngle_deg = motorController.DecodeMultiturnMotorPositionReply(data);
      sysStatus.mot_angle_yaw_deg = multiturnAngle_deg;
      // Serial.print("(Callback) YAW Motor pos: ");
      // Serial.println(multiturnAngle_deg, 3);
}


void requestMotorPositions() {


if (false) {
  /***** Non blocking (Async) position retrieval *****/

  // motorController already implements funcitonality to reject multiple requests if a request is already pending
  // so we do not need to track pending requests ourselves.
  motorController.RequestMultiturnMotorPosition_withCallback(MotorController::MOT_YAW, cb_onYawMotorPosition);
  motorController.RequestMultiturnMotorPosition_withCallback(MotorController::MOT_PITCH, cb_onPitchMotorPosition);
} else {
  /***** Blocking (Async) position retrieval *****/

  // Blocking motor-positions retrieval (not desirable as it takes ~2ms per command)

  float pitch, yaw;
  if (motorController.GetMultiturnMotorPosition_blocking(MotorController::MOT_PITCH, pitch) == MotorController::STATUS_OK) {
    sysStatus.mot_angle_pitch_deg = pitch;
  } else {
    Serial.println("ERROR: Mot pos retrieval failed_pitch");
  }

  if (motorController.GetMultiturnMotorPosition_blocking(MotorController::MOT_YAW, yaw) == MotorController::STATUS_OK) {
    //Serial.println("Updating mot_angle_yaw_deg");
    sysStatus.mot_angle_yaw_deg = yaw;
  } else {
    Serial.println("ERROR: Mot pos retrieval failed_yaw");
  }
}





}

/*
Stop motors IF:
1. Motor position is out of range (e.g., less than -45.0 or greater than 45.0 degrees).
2. Motor position retrieval fails.
3. AHRS update fails (e.g., if the sensor is not responding or if the data is invalid).

Else:
Send velocity command to motor to cancel the pitch gyro values
*/ 


void serviceCommHandlers()
{
  motorController.processCanReplies();  // Process any pending CAN replies -> Works with Async messaging
  sbcInterface.update(); // Handle UART commands from SBC
  handleSerialCommands();
}


#define MOT_ANGLE_STALE_LIMIT_US 20000 // 20ms

void loop_commtest() 
{
  loopCount++;
float pitch, yaw;
  if (motorController.GetMultiturnMotorPosition_blocking(MotorController::MOT_PITCH, pitch) == MotorController::STATUS_OK) {
    sysStatus.mot_angle_pitch_deg = pitch;
    Serial.print(".");
  } else {
    Serial.println("ERROR: Mot pos retrieval failed_pitch");
  }

  // Check every second (1,000,000 microseconds)
  if (micros() - lastTime >= 1000000) {
    Serial.print("************************************");
    Serial.print("Loop freq: ");
    Serial.print(loopCount);
    Serial.println(" Hz, ");
    loopCount = 0;
    lastTime = micros();
  }

  //delayMicroseconds(1000);

}
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

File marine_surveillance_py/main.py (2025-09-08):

#!/usr/bin/env python
"""
Maritime Surveillance System - Main Application
RK3588 with Axelera Metis M.2 + STM32 Gimbal Control
"""
import sys
import time
import signal
import threading
import os
from datetime import datetime
from typing import Optional

# Import our modules
from config import ConfigManager
from uart_comm import GimbalController
from scan_planner import ScanPlanner, ScanPosition
from camera import CameraCapture
from detector import ObjectDetector, DetectionResult
from logger import DetectionLogger
from monitor import AreaMonitor


class MaritimeSurveillanceSystem:
    """Main application orchestrator"""

    def __init__(self, config_file: str = "settings.json"):
        print("🌊 Initializing Maritime Surveillance System...")

        # Load configuration
        try:
            self.config = ConfigManager(config_file)
        except Exception as e:
            print(f"❌ Failed to load configuration: {e}")
            print("🚦 Using default configuration values")
            # Create a config manager with defaults
            self.config = ConfigManager.__new__(ConfigManager)
            self.config._config = {}

        # Validate configuration
        errors = self.config.validate_config()
        if errors:
            print("⚠️ Configuration warnings:")
            for error in errors:
                print(f"  - {error}")
            print("🚦 Continuing with default values where possible")

        # Initialize components
        self.gimbal = GimbalController(self.config)
        self.scan_planner = ScanPlanner(self.config)
        self.camera = CameraCapture(self.config)
        self.detector = ObjectDetector(self.config)
        self.logger = DetectionLogger(self.config)
        self.monitor = AreaMonitor(self.config)

        # System state
        self.running = False
        self.shutting_down = False  # Flag to prevent duplicate shutdown
        self.scan_positions: list = []
        self.current_scan_index = 0

        print("✅ System initialized successfully")

    def initialize_hardware(self) -> bool:
        """Initialize all hardware components"""
        print("🔧 Initializing hardware...")

        # Check if shutdown was requested
        if not self.running:
            print("🛑 Shutdown requested during hardware initialization")
            return False

        # Initialize gimbal communication
        if not self.gimbal.connect():
            print("❌ Failed to connect to gimbal")
            return False

        # Check if shutdown was requested
        if not self.running:
            print("🛑 Shutdown requested during hardware initialization")
            return False

        # Initialize camera
        if not self.camera.open_camera():
            print("❌ Failed to open camera")
            return False

        # Check if shutdown was requested
        if not self.running:
            print("🛑 Shutdown requested during hardware initialization")
            return False

        # Test camera
        if not self.camera.test_camera():
            print("❌ Camera test failed")
            return False

        # Check if shutdown was requested
        if not self.running:
            print("🛑 Shutdown requested during hardware initialization")
            return False

        # Initialize object detector
        if not self.detector.initialize():
            print("❌ Failed to initialize object detector")
            return False

        print("✅ Hardware initialization complete")
        return True

    def prepare_scan_plan(self) -> bool:
        """Prepare the scan plan"""
        print("📋 Preparing scan plan...")

        # Check if shutdown was requested
        if not self.running:
            print("🛑 Shutdown requested during scan planning")
            return False

        # Generate scan positions
        self.scan_positions = self.scan_planner.generate_scan_positions()

        # Note: Restricted areas are not filtered out - they are used for monitoring only
        # All positions in the scan area are included for complete coverage

        if not self.scan_positions:
            print("❌ No valid scan positions found")
            return False

        # Check if shutdown was requested
        if not self.running:
            print("🛑 Shutdown requested during scan planning")
            return False

        # Get scan statistics
        stats = self.scan_planner.get_scan_statistics(self.scan_positions)
        print("📊 Scan Plan Statistics:")
        print(f"  - Total positions: {stats['total_positions']}")
        az_range = stats['azimuth_range']
        el_range = stats['elevation_range']
        print(f"  - Azimuth range: {az_range[0]:.1f}° to {az_range[1]:.1f}°")
        print(f"  - Elevation range: {el_range[0]:.1f}° to {el_range[1]:.1f}°")
        print(f"  - Total movement: {stats['total_movement']:.1f}°")
        print(f"  - Avg movement per step: {stats['avg_movement_per_step']:.1f}°")

        print("✅ Scan plan prepared")
        return True

    def run_scan_cycle(self) -> None:
        """Run one complete scan cycle"""
        if not self.scan_positions:
            print("❌ No scan positions available")
            return

        print(f"🔄 Starting scan cycle with {len(self.scan_positions)} positions...")

        # Initialize alarm_detections for the entire cycle
        alarm_detections = []

        # Turn stabilization on before starting scan
        if not self.gimbal.set_stabilization_on():
            print("⚠️ Failed to turn stabilization on")
        time.sleep(1)  # 1s delay as requested

        for i, scan_pos in enumerate(self.scan_positions):
            if not self.running:
                break

            print(f"📍 Scanning position {i+1}/{len(self.scan_positions)}: {scan_pos}")

            # Check if shutdown was requested before starting gimbal movement
            if not self.running:
                print("🛑 Shutdown requested, aborting current scan position")
                break

            # Move gimbal to scan position
            print(f"🎯 Starting gimbal movement to {scan_pos}...")
            if not self.gimbal.move_to_position(scan_pos.azimuth, scan_pos.elevation):
                print(f"⚠️ Failed to move to position {scan_pos}, skipping...")
                continue
            print(f"✅ Gimbal movement completed for {scan_pos}")

            # Check if shutdown was requested after gimbal movement
            if not self.running:
                print("🛑 Shutdown requested, aborting current scan position")
                break
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

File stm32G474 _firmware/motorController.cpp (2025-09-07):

#include "motorController.hpp"
#include <string.h>

MotorController::PendingCanRequest MotorController::pendingRequests[MotorController::MAX_PENDING_QUEUE_SIZE] = {};




void MotorController::begin()
{
  ACANFD_STM32_Settings settings(1000 * 1000, DataBitRateFactor::x1);  
  //ACANFD_STM32_Settings settings(1000 * 1000, 50, DataBitRateFactor::x1, 50, 1000);

  Serial.print("CPU frequency: ");
  Serial.print(F_CPU);
  Serial.println(" Hz");
  Serial.print("PCLK1 frequency: ");
  Serial.print(HAL_RCC_GetPCLK1Freq());
  Serial.println(" Hz");
  Serial.print("PCLK2 frequency: ");
  Serial.print(HAL_RCC_GetPCLK2Freq());
  Serial.println(" Hz");
  Serial.print("HCLK frequency: ");
  Serial.print(HAL_RCC_GetHCLKFreq());
  Serial.println(" Hz");
  Serial.print("SysClock frequency: ");
  Serial.print(HAL_RCC_GetSysClockFreq());
  Serial.println(" Hz");
  Serial.print("FDCAN Clock: ");
  Serial.print(fdcanClock());
  Serial.println(" Hz");
 
  // settings.mModuleMode = ACANFD_STM32_Settings::EXTERNAL_LOOP_BACK ;
  settings.mModuleMode = ACANFD_STM32_Settings::NORMAL_FD;
  // settings.mModuleMode = ACANFD_STM32_Settings::INTERNAL_LOOP_BACK ;

  Serial.print("Bit Rate prescaler: ");
  Serial.println(settings.mBitRatePrescaler);
  Serial.print("Arbitration Phase segment 1: ");
  Serial.println(settings.mArbitrationPhaseSegment1);
  Serial.print("Arbitration Phase segment 2: ");
  Serial.println(settings.mArbitrationPhaseSegment2);
  Serial.print("Arbitration SJW: ");
  Serial.println(settings.mArbitrationSJW);
  Serial.print("Actual Arbitration Bit Rate: ");
  Serial.print(settings.actualArbitrationBitRate());
  Serial.println(" bit/s");
  Serial.print("Arbitration sample point: ");
  Serial.print(settings.arbitrationSamplePointFromBitStart());
  Serial.println("%");
  Serial.print("Exact Arbitration Bit Rate ? ");
  Serial.println(settings.exactArbitrationBitRate() ? "yes" : "no");
  Serial.print("Data Phase segment 1: ");
  Serial.println(settings.mDataPhaseSegment1);
  Serial.print("Data Phase segment 2: ");
  Serial.println(settings.mDataPhaseSegment2);
  Serial.print("Data SJW: ");
  Serial.println(settings.mDataSJW);
  Serial.print("Actual Data Bit Rate: ");
  Serial.print(settings.actualDataBitRate());
  Serial.println(" bit/s");
  Serial.print("Data sample point: ");
  Serial.print(settings.dataSamplePointFromBitStart());
  Serial.println("%");
  Serial.print("Exact Data Bit Rate ? ");
  Serial.println(settings.exactDataBitRate() ? "yes" : "no");

  //--- beginFD is called without any receive filter, all sent frames are received
  //    by receiveFD0 throught receiveFIFO0

  uint32_t errorCode;
  /*
  uint32_t errorCode = fdcan1.beginFD (settings) ;
  if (0 == errorCode) {
    Serial.println ("fdcan1 configuration ok") ;
  }else{
    Serial.print ("Error fdcan1: 0x") ;
    Serial.println (errorCode, HEX) ;
  }
  */

  errorCode = fdcan2.beginFD(settings);
  if (0 == errorCode)
  {
    Serial.println("fdcan2 configuration ok");
  }
  else
  {
    Serial.print("Error fdcan2: 0x");
    Serial.println(errorCode, HEX);
  }
}


int MotorController::SendCanMessageToMotorAndReturnReplyBlocking(uint motor_id, uint8_t *cmd_data)
{
  uint8_t sentCmd = cmd_data[0];

  CANMessage message;
  message.ext = false;   // Standard message
  message.id = motor_id; // Motor IDs: 0x140 + 1/2/3..8
  message.len = 8;       // Always 8 bytes

  memcpy(message.data, cmd_data, message.len);

  //--- tryToSendReturnStatusFD returns 0 if message has been successfully
  //    appended in transmit buffer.
  //  A not zero returned value contains an error code (see doc)
  uint32_t sendStatus = fdcan2.tryToSendReturnStatusFD(message);
  if (sendStatus != 0)
  {
    can_tx_failed_count++;
    return STATUS_FAILED;
  }
    
  /*else
  {
    gSentCount1 += 1 ;
    Serial.print ("fdcan1 sent: ") ;
    Serial.println (gSentCount1) ;
  }*/

  // delay(2); //in ms; TODO: Remove/tune
  delayMicroseconds(2000);

  CANFDMessage rx_frame;
  if (fdcan2.receiveFD0(rx_frame))
  {
    // Make sure it's the reply for same message, from same motor
    if ((rx_frame.id == motor_id) && (rx_frame.data[0] == sentCmd) && rx_frame.len == 8)
    {
      // Copy the received data back into cmd_data
      memcpy(cmd_data, rx_frame.data, rx_frame.len);
      return STATUS_OK;
    }
  }
  // If execution reaches here, means something failed.
  return STATUS_FAILED;
}


// To be called repeatedly in loop() to process CAN replies
// This function checks for any CAN messages received and matches them to pending requests.
// Also removes stale requests that have not been completed within a certain timeout period.
void MotorController::processCanReplies()
{
    CANFDMessage rx_frame;
    uint32_t now = _micros();

    // 1. Reply handling (process all received messages first)
    while (fdcan2.receiveFD0(rx_frame)) {
        can_rx_count++;
        bool matched = false;
        for (int i = 0; i < MAX_PENDING_QUEUE_SIZE; ++i) {
            if (pendingRequests[i].in_use &&
                rx_frame.id == pendingRequests[i].motor_id &&
                rx_frame.data[0] == pendingRequests[i].cmd_id &&
                rx_frame.len == 8) {
                can_rx_good_count++;
                memcpy(pendingRequests[i].reply_buffer, rx_frame.data, 8);
                if (pendingRequests[i].callback) 
                {
                    pendingRequests[i].callback(rx_frame.id, STATUS_OK, rx_frame.data);
                }
                pendingRequests[i].in_use = false;
                pendingRequests[i].callback = nullptr;
                matched = true;
                break;
            }
        }
        if (!matched) {
            can_rx_unknown++;
            if (DEBUG_MOT_CTRL) {
                Serial.print("Unknown reply from motor ID: ");
                Serial.print(rx_frame.id, HEX);
                Serial.print(" Data: ");
                for (int j = 0; j < rx_frame.len; ++j) {
                    Serial.print(rx_frame.data[j], HEX);
                    Serial.print(" ");
                }
            }
        }
    }

    // 2. Timeout handling (now only mark as timeout if reply wasn't already processed)
    // NOTE: This MUST be done AFTER handling all messages already in receive buffer
    // so that an older request is not marked stale if reply already exists in receive buffer (bug earlier)
    for (int i = 0; i < MAX_PENDING_QUEUE_SIZE; ++i) {
        if (pendingRequests[i].in_use &&
            (now - pendingRequests[i].timestamp_us > SETTING_MAX_REQUEST_AGE_US)) {
            if (pendingRequests[i].callback) {
                pendingRequests[i].callback(pendingRequests[i].motor_id, STATUS_TIMEOUT, nullptr);
            }
            pendingRequests[i].in_use = false;
            pendingRequests[i].callback = nullptr;
            can_no_rep_count++;
        }
    }
}
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

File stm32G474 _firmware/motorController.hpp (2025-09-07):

//-----------------------------------------------------------------
// This demo runs on WeActStudio STM32G474CEU6 board
// https://github.com/WeActStudio/WeActStudio.STM32G474CoreBoard
// The can clock frequency is 170 MHz.
// The 3 FDCAN modules are configured in external loop back mode: it
// internally receives every CAN frame it sends, and emitted frames
// can be observed on TxCAN pins. No external hardware is required.
// Default TxCAN pins are used:
//   - fdcan1: PA_12
//   - fdcan2: PB_6
//   - fdcan3: PA_15
//-----------------------------------------------------------------

#ifndef ARDUINO_WEACT_G474CE
  #error This sketch runs on WeActStudio STM32G474CEU6 board
#endif

//-----------------------------------------------------------------
// IMPORTANT:
//   <ACANFD_STM32.h> should be included only once in a sketch, generally from the .ino file
//   From an other file, include <ACANFD_STM32_from_cpp.h>
//-----------------------------------------------------------------

//#include <ACANFD_STM32.h>
#include <ACANFD_STM32_from_cpp.h>
extern ACANFD_STM32 fdcan2; // Since the <ACANFD_STM32.h> is included from .ino sketch
//-----------------------------------------------------------------

#ifndef MOTOR_CONTROLLER_HPP
#define MOTOR_CONTROLLER_HPP


#include <Arduino.h>
#include "time_utils.hpp"

typedef void (*MotorReplyCallback)(uint motor_id, int status, const uint8_t* data);


class MotorController {
public:
    // CAN IDs
    static constexpr uint16_t MOT1_CAN_ID = 0x140 + 1;
    static constexpr uint16_t MOT2_CAN_ID = 0x140 + 2;

    // Canonical Names for motors
    #define MOT_PITCH MOT1_CAN_ID
    #define MOT_YAW   MOT2_CAN_ID

    // Command codes
    static constexpr uint8_t RMD_CAN_CMD_SET_POS_MULTITURN_SPD_LIM = 0xA4;
    static constexpr uint8_t RMD_CAN_CMD_GET_POS_MULTITURN = 0x92;
    static constexpr uint8_t RMD_CAN_CMD_SET_TORQUE_CURRENT = 0xA1;
    static constexpr uint8_t RMD_CAN_CMD_SET_VELOCITY = 0xA2;

    bool DEBUG_MOT_CTRL = true; // Set to true to enable debug prints

    // Status codes
    static constexpr int STATUS_OK = 0;
    static constexpr int STATUS_FAILED = -1;

    static constexpr int STATUS_TIMEOUT = -2; // Timeout waiting for reply


    MotorController() = default;
    void begin();    

    static float DecodeMultiturnMotorPositionReply(const uint8_t *data);
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
